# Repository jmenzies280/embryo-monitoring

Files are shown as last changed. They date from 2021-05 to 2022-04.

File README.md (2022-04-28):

# Drosophila embryo monitoring system

This is a small video system to monitor the development of Drosophila embryos.

--- 

## Hardware:

|Qty|item|obs|link|
|--|--|--|--|
|1|200mm makerbeam XL aluminium profiles|pieces to hold the grid that will contain the embryos aluminium profiles||
|2|100mm makerbeam XL aluminium profiles|camera mounting frame||
|2|150mm makerbeam XL aluminium profiles|camera mounting frame||
|4|"L" bracket makerbeam XL|holds the aluminium profiles together||
|1|3D printed embryo grid|initially printed in black PLA||
|18|M3 5mm screws| holds maker beams and other bits together||
|14|M3 nuts|used together with screws||

---

## Software:
  
  - For this system we used Bonsai-RX to control the camera, as it allows for flexibility in determining time lapse rates and movement tracking of the embryos. 

--- 

## Setup images:

|||
|--|--|
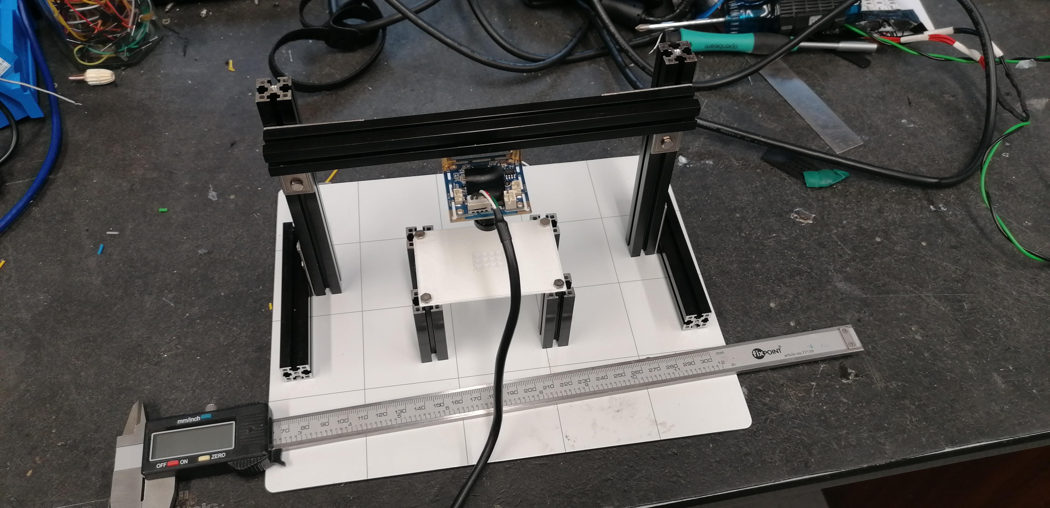
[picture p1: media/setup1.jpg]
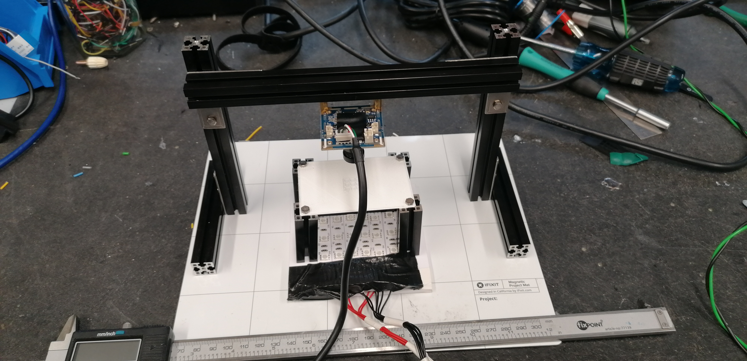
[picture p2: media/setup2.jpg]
|||

---

## Some initial taken with the setup images:

- note: the printer used to make the grid in the images below was poorly calibrated, the final grid looks much better.

||empty|water|
|--|--|--|
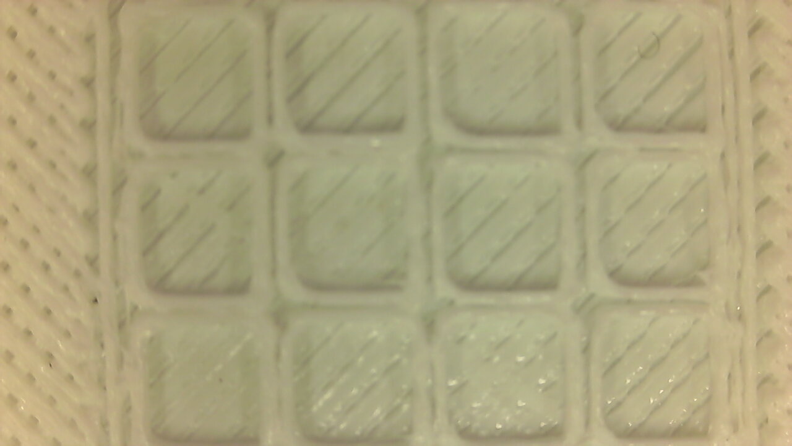
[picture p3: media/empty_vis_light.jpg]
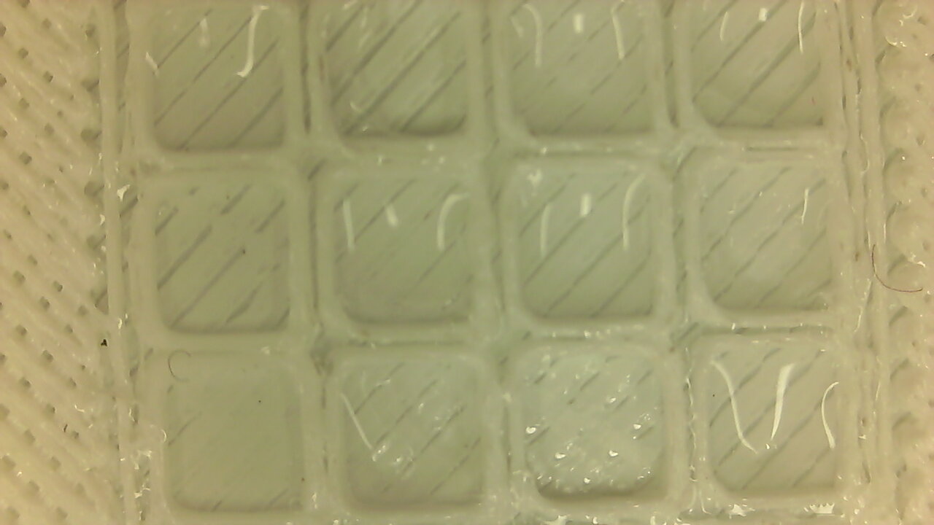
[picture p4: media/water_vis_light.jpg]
|Visible light|||
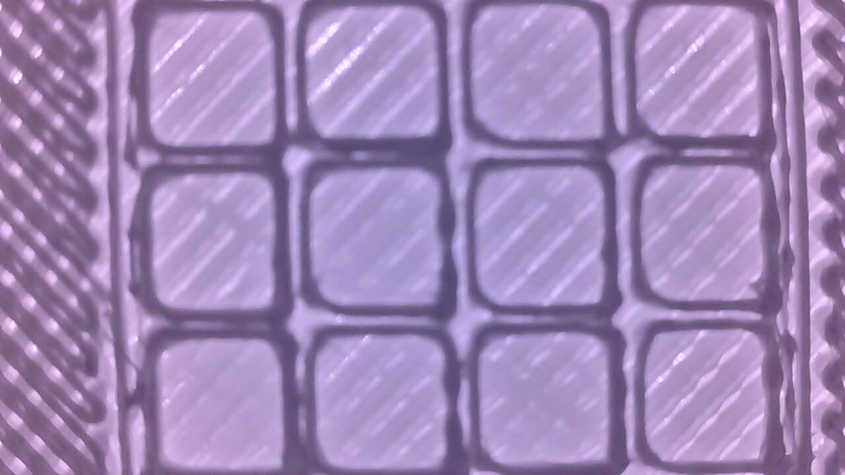
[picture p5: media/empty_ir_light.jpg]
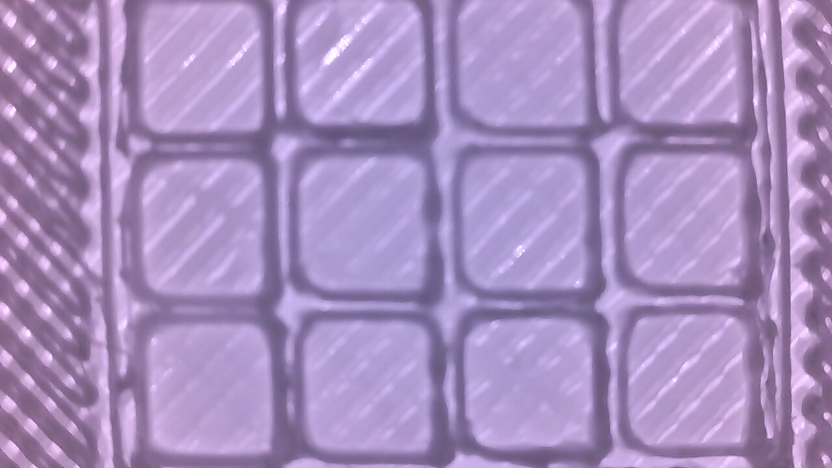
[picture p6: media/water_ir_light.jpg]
|Infra red light|||

## TODO:

### Software analysis:
- Create a jupyter notebook to process the data
 - Subtract running average from brightness average.
 - square square root (so that all values are positive)
 - find hatching point of the embryos (they poke out their heads at the top of the egg shell). This leads normally to a peak on the values of the traces. (maybe shape of the egg.)

  - parameters that are calculated from traces:
   - total movement (sum all of the values above a threshold)
   - percentage time moving (number of frames where movement is above the threshold)
   - average movement amplitude (average of movement above a certain threshold)
   - time between first movement and hatching
   - phases movement 
     - high frequency (slow increase and slow decrease)
     - bursts of movement
   - fft analysis
    - bin traces into 30min periods and show how frequency content changes in each bin 

### Hardware:

- test different cameras and lighting conditions

- Optogenetics led:
- LED ring turning on the red channel for 500 ms every 30 seconds.

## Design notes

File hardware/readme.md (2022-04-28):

https://grabcad.com/library/adafruit-neopixel-ring-12x-ws2812-rgb-leds-1

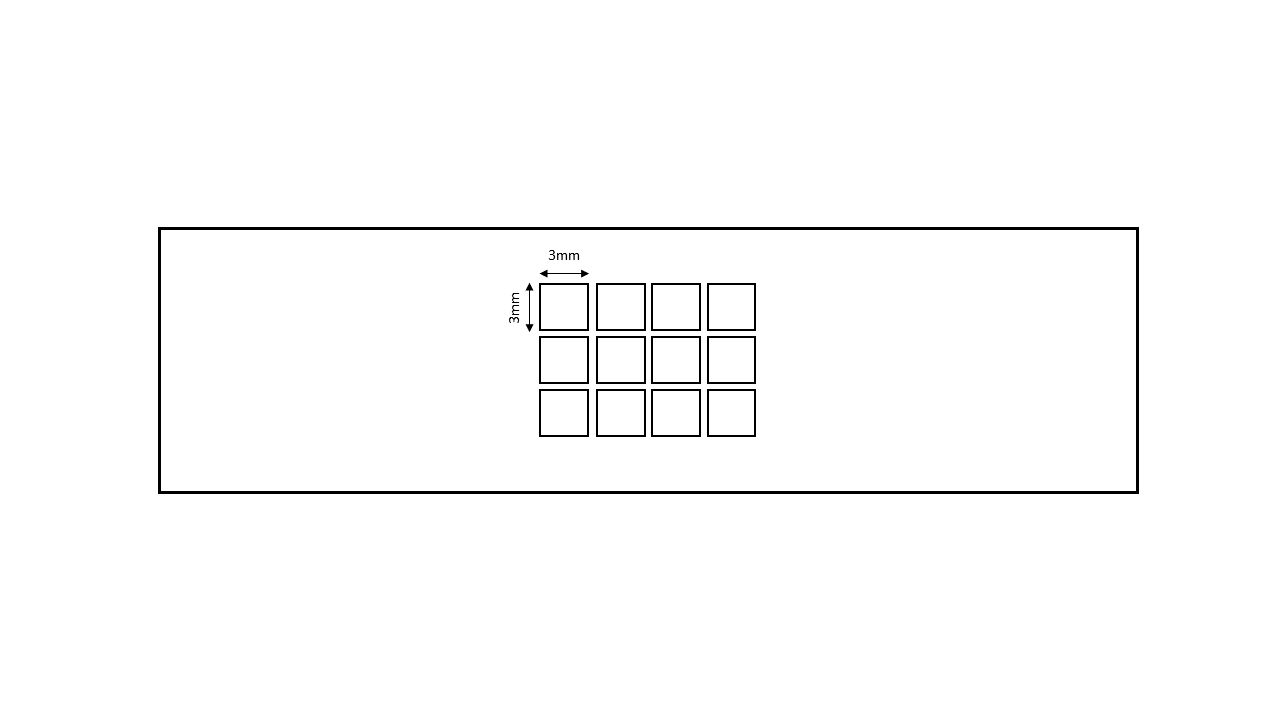
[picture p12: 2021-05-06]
media/Ideal oocyte grid.png

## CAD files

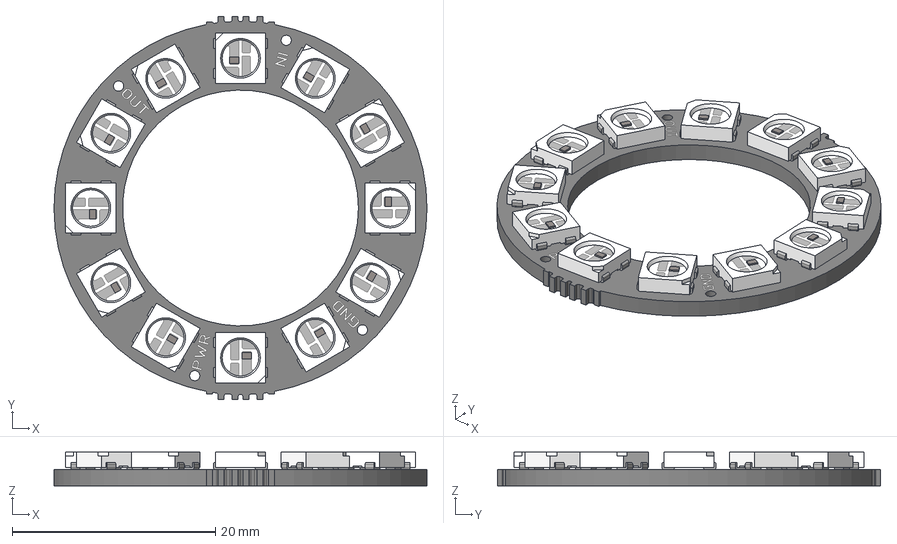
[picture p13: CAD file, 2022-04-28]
hardware/adafruit-neopixel-ring-12x-ws2812-rgb-leds-1/Adafruit neopixel ring.stp
36.7 x 37.7 x 3.31 mm

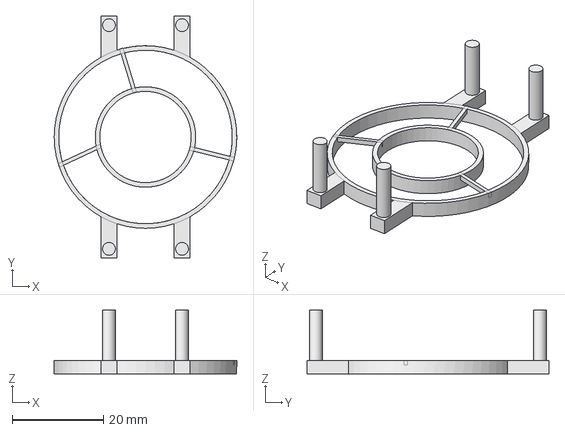
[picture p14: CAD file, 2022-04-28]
hardware/led_holder.FCStd
40.0 x 53.0 x 14.0 mm

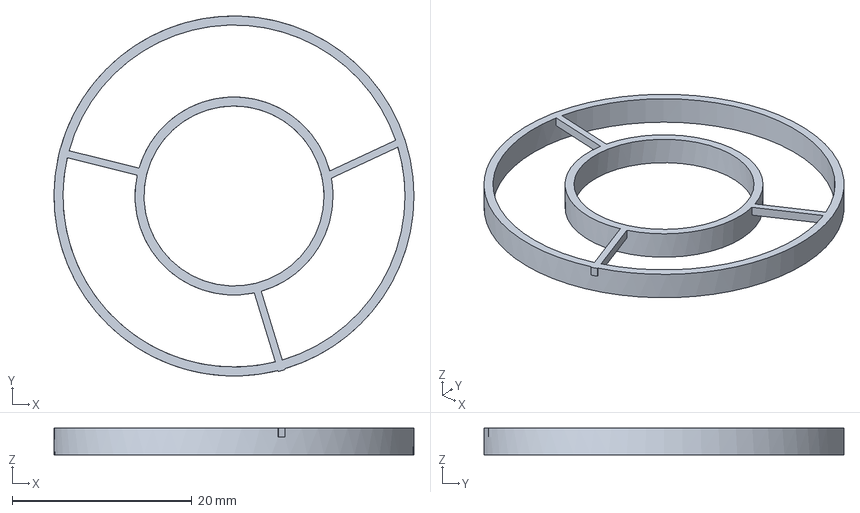
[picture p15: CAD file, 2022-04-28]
hardware/led_ring_holder.amf
40.0 x 40.0 x 3.00 mm

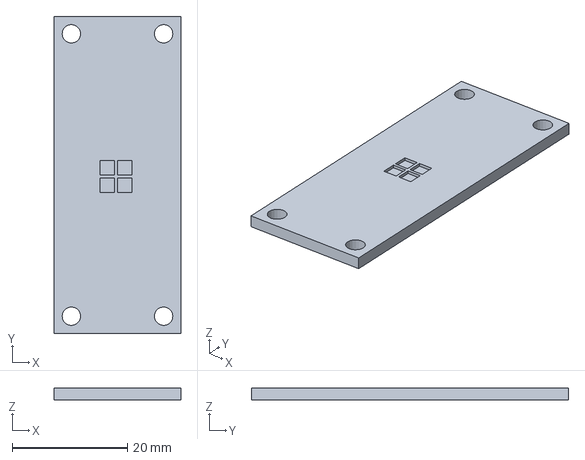
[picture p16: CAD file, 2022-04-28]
hardware/oocyte_grid.amf
22.0 x 55.0 x 2.00 mm

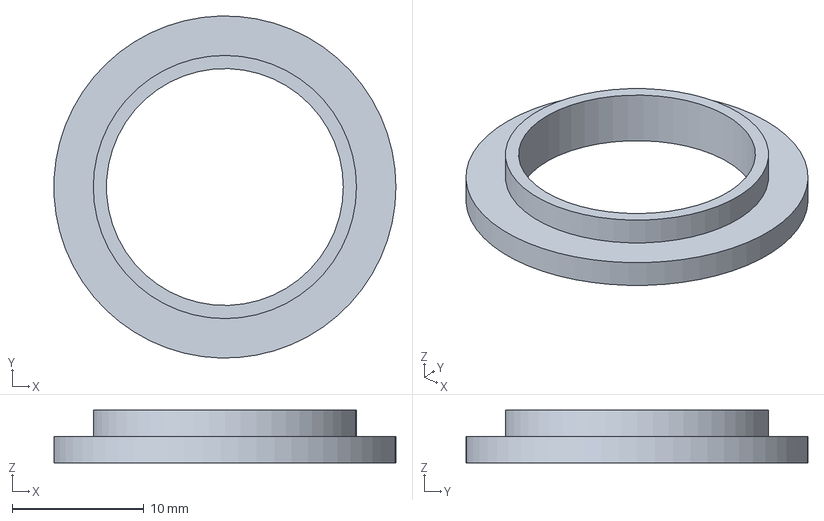
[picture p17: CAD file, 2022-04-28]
hardware/led_ring_fixer.amf
26.0 x 26.0 x 4.00 mm

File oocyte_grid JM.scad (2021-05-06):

//oocyte chamber
//updated by AM Chagas 20210506 -> larger grid
//designed by AM Chagas 20181001 CC BY 4.0 license
//inspired on the design from J Menzies.

wellx = 3;
welly = 3;
wellz = 0.8;
interwell = 0.24;
nwellsx = 3;
nwellsy = 4;

platey = wellx*nwellsx*5;
platex = welly*nwellsy*1.5    ;
platez = 2;


module grid(){
    for (x = [0:nwellsx-1]){
        for (y = [0:nwellsy-1]){
            translate([x*(wellx+interwell),y*(welly+interwell),0]){
                cube([wellx,welly,wellz]);
                }//end translate
            }//end for y
    }//end for x
}//end module

difference(){
translate([0,0,-platez/2]){
cube([platex,platey,platez],center=true);
}//end translate
translate([-(nwellsx*(wellx+interwell))/2,-(nwellsy*(welly+interwell))/2,-wellz+0.01]){
grid();
}//end translate
}//end difference

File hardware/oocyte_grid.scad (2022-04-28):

//oocyte chamber
//updated by AM Chagas 20210506 -> larger grid
//designed by AM Chagas 20181001 CC BY 4.0 license
//inspired on the design from J Menzies.

wellx = 2.5;
welly = 2.5;
wellz = 0.5;
interwell = 0.5;
nwellsx = 2;
nwellsy = 2;

platey = wellx*nwellsx*5+30;
platex = welly*nwellsy*1.5+14.5;
platez = 2;

screwD = 3;
screwH = 10;

legL=40;
legD=8;


tol = 0.1;
$fn=20;
module grid(){
    for (x = [0:nwellsx-1]){
        for (y = [0:nwellsy-1]){
            translate([x*(wellx+interwell),y*(welly+interwell),0]){
                cube([wellx,welly,wellz]);
                }//end translate
            }//end for y
    }//end for x
}//end module

module plate(){
difference(){
translate([0,0,-platez/2]){
cube([platex,platey,platez],center=true);
}//end translate
translate([-(nwellsx*(wellx+interwell))/2,-(nwellsy*(welly+interwell))/2,-wellz+0.01]){
grid();
}//end translate
}//end difference

}//end module

module grid_w_holes(){
difference(){
plate();

translate([platex/2-screwD,platey/2-screwD,-screwH/2])
cylinder(d=screwD+2*tol,h=screwH);

translate([-platex/2+screwD,platey/2-screwD,-screwH/2])
cylinder(d=screwD+2*tol,h=screwH);

translate([-platex/2+screwD,-platey/2+screwD,-screwH/2])
cylinder(d=screwD+2*tol,h=screwH);

translate([platex/2-screwD,-platey/2+screwD,-screwH/2])
cylinder(d=screwD+2*tol,h=screwH);

}//end difference


}//end module

module grid_w_legs(){
    plate();
    
    translate([platex/2-legD,platey/2-legD,-legL])
cube([legD,legD,legL]);

translate([-platex/2,platey/2-legD,-legL])
cube([legD,legD,legL]);

translate([-platex/2,-platey/2,-legL])
cube([legD,legD,legL]);

translate([platex/2-legD,-platey/2,-legL])
cube([legD,legD,legL]);
    
    }

//grid_w_legs();
grid_w_holes();

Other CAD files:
hardware/raised_led_holder.amf
hardware/adafruit-neopixel-ring-12x-ws2812-rgb-leds-1/Adafruit neopixel ring.igs
hardware/adafruit-neopixel-ring-12x-ws2812-rgb-leds-1/Neopixel Ring 12x.x_t

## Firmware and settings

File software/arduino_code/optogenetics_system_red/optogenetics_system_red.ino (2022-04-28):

#include <Adafruit_NeoPixel.h>
#include <SerialCommand.h>
// Which pin on the Arduino is connected to the NeoPixels?
#define LED_PIN    9

// How many NeoPixels are attached to the Arduino?
#define LED_COUNT 12
// Declare our NeoPixel strip object:
Adafruit_NeoPixel strip(LED_COUNT, LED_PIN, NEO_RGBW + NEO_KHZ800);
// Argument 1 = Number of pixels in NeoPixel strip
// Argument 2 = Arduino pin number (most are valid)
// Argument 3 = Pixel type flags, add together as needed:
//   NEO_KHZ800  800 KHz bitstream (most NeoPixel products w/WS2812 LEDs)
//   NEO_KHZ400  400 KHz (classic 'v1' (not v2) FLORA pixels, WS2811 drivers)
//   NEO_GRB     Pixels are wired for GRB bitstream (most NeoPixel products)
//   NEO_RGB     Pixels are wired for RGB bitstream (v1 FLORA pixels, not v2)
//   NEO_RGBW    Pixels are wired for RGBW bitstream (NeoPixel RGBW products)

SerialCommand sCmd;     // The demo SerialCommand object

float timeOff = 5;
float timeOn = 1;
int brightRed = 0;
int brightBlue = 0;
int brightWhite = 0;
int repetitions = 2;
int flag=1;

void setup() {
  // put your setup code here, to run once:
Serial.begin(9600);

strip.begin();
strip.show(); // Initialize all pixels to 'off'

sCmd.addCommand("white",    white);
sCmd.addCommand("blueon",    blue_on);
sCmd.addCommand("blueoff",    blue_off);
sCmd.addCommand("on",    start);
sCmd.addCommand("config", config);
//sCmd.addCommand("time",    time);
sCmd.addCommand("HELLO", sayHello);        // Echos the string argument back
sCmd.addCommand("P",     processCommand);  // Converts two arguments to integers and echos them back
//sCmd.setDefaultHandler(unrecognized);      // Handler for command that isn't matched  (says "What?")


}//end setup

void loop() {
  // put your main code here, to run repeatedly:
sCmd.readSerial();     // We don't do much, just process serial commands
if (flag==1){
Serial.println("string format: 'on timeOn timeOff brightness repetitions' ");
flag=0;
}



}//end loop

void white(){
  //int aNumber;
  char *arg;
  arg = sCmd.next();
  if (arg != NULL) {
    brightWhite = atoi(arg);    // Converts a char string to an integer
  }
    Serial.print("White brightness: ");
    Serial.println(brightWhite);
    
    for (int i = 0; i <=  LED_COUNT; i=i+1){
      strip.setPixelColor(i, 0, brightRed, brightBlue,brightWhite);
      }//end for
    strip.show();
  
  
}


void blue_on(){
  //int aNumber;
  char *arg;
  arg = sCmd.next();
  if (arg != NULL) {
    brightBlue = atoi(arg);    // Converts a char string to an integer
  }
    Serial.print("blue brightness: ");
    Serial.println(brightBlue);
    
    for (int i = 0; i <=  LED_COUNT; i=i+1){
      strip.setPixelColor(i, 0, brightRed, brightBlue,0);
      }//end for
    strip.show();
  
  
}
void blue_off(){
      for (int i = 0; i <=  LED_COUNT; i=i+1){
      strip.setPixelColor(i, 0, brightRed, 0,0);
      }//end for
    strip.show();
  }
void start(){
int aNumber;
  //float timeOn;
  //float timeOff;
  //int brightRed;
  int repetitions;
  char *arg;

  Serial.println("load values:");
  
  arg = sCmd.next();
  if (arg != NULL) {
    timeOn = atof(arg);    // Converts a char string to an integer
    Serial.print("time on: ");
    Serial.println(timeOn);
  }
 
  
  arg = sCmd.next();
  if (arg != NULL) {
    timeOff = atof(arg);
    Serial.print("time off: ");
    Serial.println(timeOff);
  }
  
  arg = sCmd.next();
  if (arg != NULL) {
    brightRed = atoi(arg);
    if (brightRed>255){brightRed=255;}
    if (brightRed<0){brightRed=0;}
    Serial.print("brightness red: ");
    Serial.println(brightRed);
  }

  
  arg = sCmd.next();
  if (arg != NULL) {
    repetitions = atoi(arg);
    Serial.print("repetitions: ");
    Serial.println(repetitions);
  }

  Serial.println("starting in 1 second");
  delay(1000);

  for (int j = 0; j<repetitions; j=j+1){
    for (int i = 0; i <=  LED_COUNT; i=i+1){
      strip.setPixelColor(i, 0, brightRed, brightBlue,0);
      }//end for
    strip.show();
    delay(timeOn*1000);

    for(int i=0; i<= LED_COUNT; i=i+1){
      strip.setPixelColor(i, 0, 0, brightBlue,0);
      }//end for
    strip.show();
    delay(timeOff*1000);

  }//end j
brightRed=0;
}//end blink



// This gets set as the default handler, and gets called when no other command matches.
void unrecognized(const char *command) {
  Serial.println("What?");
}

void sayHello() {

  char *arg;
  arg = sCmd.next();    // Get the next argument from the SerialCommand object buffer
  if (arg != NULL) {    // As long as it existed, take it
    Serial.print("Hello ");
    Serial.println(arg);
  }
  else {
    Serial.println("Hello, whoever you are");
  }
}


void processCommand() {
  int aNumber;
  char *arg;

  Serial.println("We're in processCommand");
  arg = sCmd.next();
  if (arg != NULL) {
    aNumber = atoi(arg);    // Converts a char string to an integer
    Serial.print("First argument was: ");
    Serial.println(aNumber);
  }
  else {
    Serial.println("No arguments");
  }

  arg = sCmd.next();
  if (arg != NULL) {
    aNumber = atol(arg);
    Serial.print("Second argument was: ");
    Serial.println(aNumber);
  }
  else {
    Serial.println("No second argument");
  }
}//end process command

void config() {
  int aNumber;
  float timeOn;
  float timeOff;
  int bright;
  int repetitions;
  char *arg;

  Serial.println("configure protocol");
  Serial.println("time on in seconds");
  arg = sCmd.next();
  if (arg != NULL) {
    timeOn = atof(arg);    // Converts a char string to an integer
    //Serial.print("First argument was: ");
    //Serial.println(aNumber);
  }
  else {
    Serial.println("No arguments");
  }
  
  Serial.println("time off in seconds");
  arg = sCmd.next();
  if (arg != NULL) {
    timeOff = atof(arg);
    //Serial.print("Second argument was: ");
    //Serial.println(aNumber);
  }
  Serial.println("brightness (255 is max bright)");
  arg = sCmd.next();
  if (arg != NULL) {
    bright = atoi(arg);
    //Serial.print("Second argument was: ");
    //Serial.println(aNumber);
  }

  Serial.println("number of repetitions");
  arg = sCmd.next();
  if (arg != NULL) {
    repetitions = atoi(arg);
    //Serial.print("Second argument was: ");
    //Serial.println(aNumber);
  }
  else {
    Serial.println("No second argument");
  }
}//end process command

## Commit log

2021-05-06 work on oocyte grid
    [oocyte_grid JM.scad]
2021-07-08 start documentation, add images of built system, update embryo grid
    [oocyte_grid.scad, oocyte_grid.stl]
2021-07-27 add bonsai code to record
    [oocyte_grid.scad]
2021-09-22 update oocyte holders
    [oocyte_grid_holes.stl, oocyte_grid_legs.stl]
2021-10-11 update scad file
    [oocyte_grid.scad]
2021-11-01 add sample csv file
2021-11-05 update bonsai and store sample analysis output
    [test2021-11-05T16_06_12.csv]
2021-12-07 create arduino sketch to control Adafruit LED ring
2021-12-09 update arduino code and analysis code
2022-01-19 update bonsai code to output average brightness, roi width and height
    [test2021-11-05T16_06_12.csv]
2022-01-26 first work on the led holder
    [Adafruit neopixel ring.igs, Adafruit neopixel ring.stp, Neopixel Ring 12x.x_t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]
2022-02-28 update code and some readme
    [led_holder.FCStd, oocyte_grid.amf, oocyte_grid.scad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]
